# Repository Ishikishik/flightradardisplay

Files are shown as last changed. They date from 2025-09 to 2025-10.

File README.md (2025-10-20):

# フライトレーダー表示プロジェクト

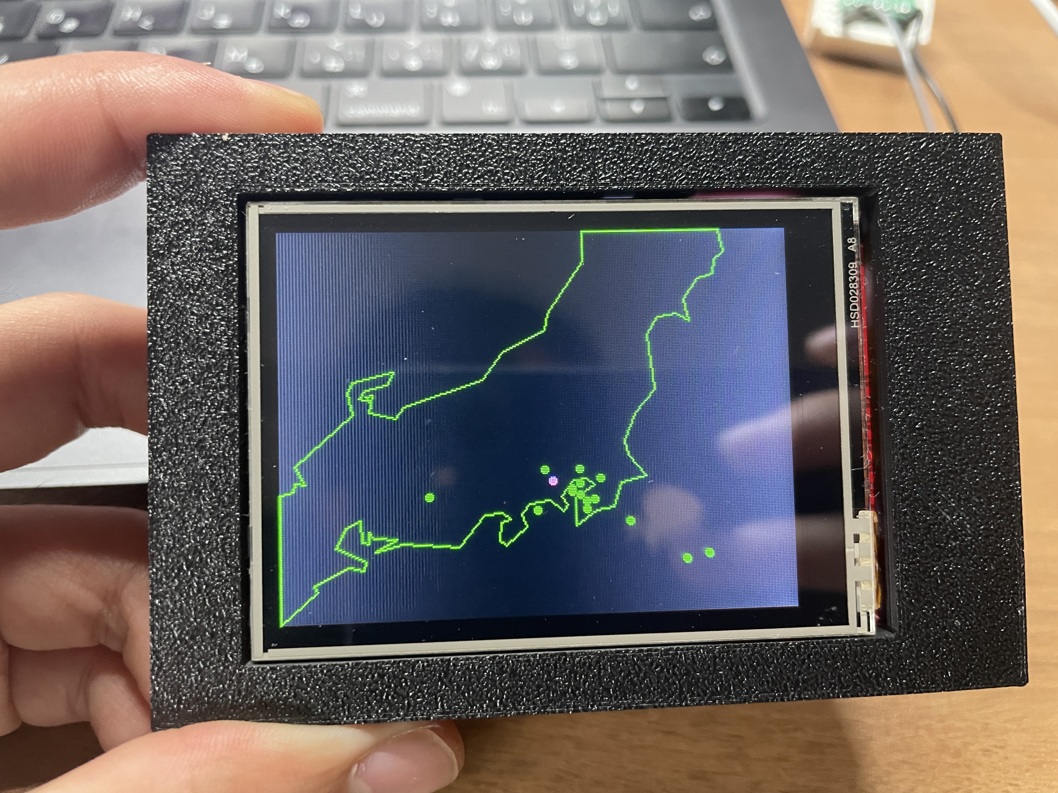
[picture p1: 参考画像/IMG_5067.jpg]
代替テキスト

代替テキスト

ESP32-C3 と小型液晶ディスプレイを使い、**フライトレーダーのフィード状況を表示するデバイス**です。  
ラズベリーパイを使った例よりも、**安価かつコンパクト**に構築できます。

---

## 使用部品

| 部品 | 説明・購入先 |
| ---- | --- |
| [ESP32-C3](https://akizukidenshi.com/catalog/g/g117493/) | メインマイコン |
| [1.54インチ TFT 液晶](https://akizukidenshi.com/catalog/g/g116265/) | 地図・便名表示用 |
| [USB Type-C コネクタ DIP 化キット](https://akizukidenshi.com/catalog/g/g115426/) | 電源・書き込み用 |
| コンデンサ / 抵抗 / 3端子レギュレータ | 電源安定化などに適宜使用 |
|ロータリースイッチ | 型番不明 |

---

## コード構成

### 1. 地図生成ツール(makemap)
- **`makemap.py`**  
  指定した緯度・経度範囲の白黒地図を生成します。  
  ご自分の地域に合わせてパラメータを設定してください。
- **`tolist.py`**  
  生成した白黒地図を **LCD に描画しやすい線形データ** に変換します。

### 2. 本体コード `kawaeyes`
- **`kawaeyes.ino`**  
  ESP32-C3 で動作するメインプログラム。
- **`library.cpp`**  
  - `setupwifi()`：Wi-Fi 接続処理  
  - `showairplane()`：飛行機の位置と便名を地図上に表示  
  - `showjson()`：便名と位置を文字のみで表示
- **`mapdata.cpp`**  
  東京都調布市（カワウソの住処）を例に `makemap` で生成した地図データ。

- **`secret.hpp`**  
  **Wi-Fi の SSID / パスワード / フィーダーの IP を定義するため、作成してください。**  
  下記の例を参考に、自分の環境に合わせて内容を編集します。

  ```cpp
  #ifndef SECRET_HPP
  #define SECRET_HPP

  #define SSID ""    // Wi-Fi SSID
  #define PASS ""    // Wi-Fi パスワード
  #define IP   ""    // フィーダーの IP
                          // 例: http://<IP>:8754/flights.json
                          // もしエンドポイントが異なる場合は
                          // getjson.cpp 内の showjson() を調整してください

  #endif

### 3. その他(hard,参考画像)
- **`hard`**  
  筐体の3Dデータ(.scadと.stlがある)
- **`参考画像`**  
  基板データはないがエクストリーム配線の様子を備忘録として残す。

  - **`repeater_flightradar`**  
  外でこの装置を動かしたい時に[このリポジトリ](https://github.com/Ishikishik/repeater_flightradar)をチェック!
  tailscaleに入ったpc(中間サーバー)からjsonをインターネットに公開して、他のネットワークからでもjsonを取得できる様にします。

---

## 参考リンク
- [LovyanGFX ライブラリ（LCD制御）](https://github.com/lovyan03/LovyanGFX)
- [ESP32 書き込み手順 (Qiita)](https://qiita.com/McbeEringi/items/b791399b03aba0929368)

---

## 使い方

1. **地図データ作成**  
   `makemap.py` で範囲を指定して白黒地図を生成 → `tolist.py` で LCD 用データに変換。

2. **ESP32-C3 へ書き込み**  
   生成した `mapdata.cpp` をプロジェクトに追加し、`kawaeyes.ino` をビルド＆書き込み。

3. **起動**  
   電源投入後、自動的に Wi-Fi へ接続し、フライトレーダーのフィードを取得して地図上に便名と位置を表示します。

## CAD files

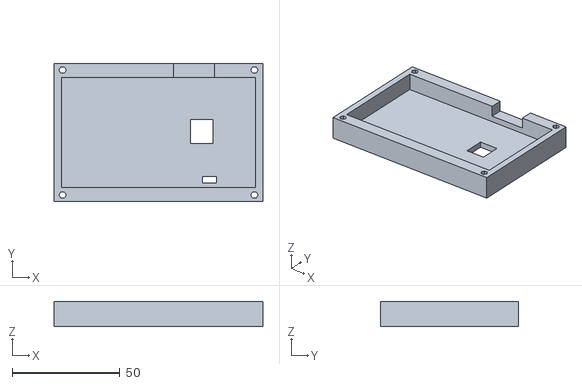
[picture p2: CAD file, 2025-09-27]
hard/under.stl
97.0 x 64.0 x 11.8

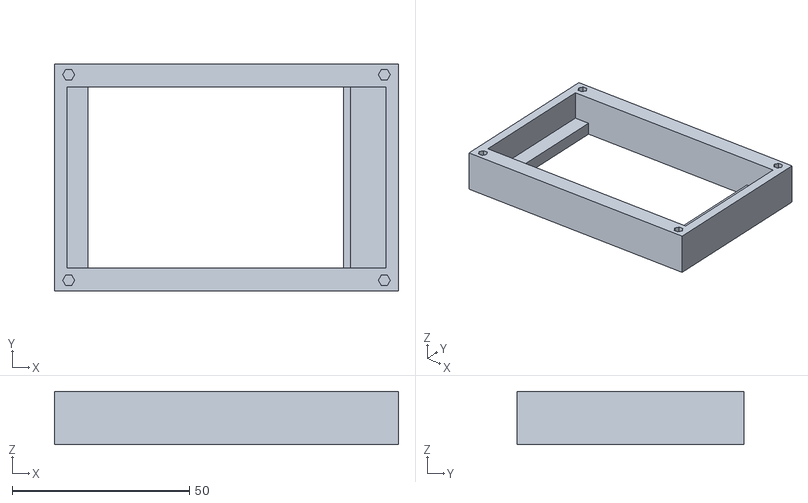
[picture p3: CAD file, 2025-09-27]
hard/top.stl
97.0 x 64.0 x 15.0

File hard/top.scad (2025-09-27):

//頭4.8(2.4)(2.9)mmネジ3.4(1.7)mmナット5.8(2.9)(3.4)mm
difference() {
    // 外枠（厚み6.5mm）
    cube([97, 64,15 ], center = true);//外装

    //ディスプレイ部
    translate([-3,0,-7.5])
    cube([72, 51,9], center = true);

    //本体部
    translate([0,0,7.5])
    cube([90, 51,21], center = true);

    //アンテナ部
    translate([0,0,7.5])
    cube([69.5, 51,4], center = true);

    //横端子部
    translate([40,0,0])
    cube([10, 51,12], center = true);


    //ネジ
    translate([95/2-3,60/2-1,0])
    cylinder(h = 10, r = 1.7, center = false);

    translate([-(95/2-3),60/2-1,0])
    cylinder(h = 10, r = 1.7, center = false);

    translate([95/2-3,-(60/2-1),0])
    cylinder(h = 10, r = 1.7, center = false);

    translate([-(95/2-3),-(60/2-1),0])
    cylinder(h = 10, r = 1.7, center = false);



   
}

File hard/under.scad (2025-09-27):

//頭4.8(2.4)(2.9)mmネジ3.4(1.7)mmナット5.8(2.9)(3.4)mm
//頭4.8(2.4)(2.9)mmネジ3.4(1.7)mmナット5.8(2.9)(3.4)mm
difference() {

    // 外枠（厚み6.5mm）
    translate([0,0,0])
    cube([97, 64,11.8 ], center = true);//外装


    //本体部
    translate([0,0,1.5])
    cube([90, 51,8.8], center = true);

    translate([90/2-21.4,-(64/2)+10,0])
    cube([6.5, 3,100], center = true);//端子

    translate([90/2-24.9,-(64/2)+32.5,0])
    cube([10.4, 11,100], center = true);//ロータリースイッチ

    translate([90/2-28.5,64/2,3.1])
    cube([19, 30,5.7], center = true);//アンテナ


    //ネジ
    translate([95/2-3,60/2-1,-20])
    cylinder(h = 100, r = 1.7, center = false);

    translate([-(95/2-3),60/2-1,-20])
    cylinder(h = 100, r = 1.7, center = false);

    translate([95/2-3,-(60/2-1),-20])
    cylinder(h = 100, r = 1.7, center = false);

    translate([-(95/2-3),-(60/2-1),-20])
    cylinder(h = 100, r = 1.7, center = false);

        //ネジ頭
    translate([95/2-3,60/2-1,-(11.8/2)])
    cylinder(h = 2, r = 3, center = false);

    translate([-(95/2-3),60/2-1,-(11.8/2)])
    cylinder(h = 2, r = 3, center = false);

    translate([95/2-3,-(60/2-1),-(11.8/2)])
    cylinder(h = 2, r = 3, center = false);

    translate([-(95/2-3),-(60/2-1),-(11.8/2)])
    cylinder(h = 2, r = 3, center = false);



   
}

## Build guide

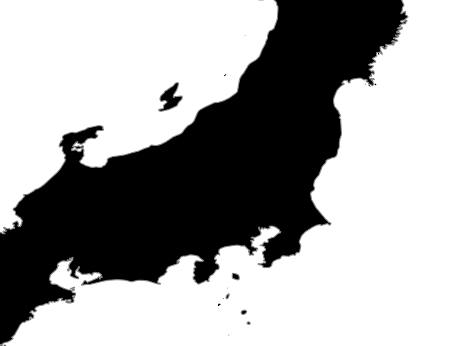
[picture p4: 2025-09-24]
makemap/map.png

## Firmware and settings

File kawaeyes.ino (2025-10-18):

#include <LovyanGFX.hpp>
#include "lgfxesp32c3.hpp"
#include "mapdata.hpp"
#include "library.hpp"
#include "secret.hpp"

MyLGFX lcd;  // LGFX → MyLGFX に変更
LGFX_Sprite mapSprite(&screenSprite);
LGFX_Sprite planeSprite(&screenSprite);
LGFX_Sprite screenSprite(&lcd);  // 新規スプライト

const float lon_min = 135.755; //画面西(左)端の経度
const float lon_max = 142.954; //画面東(右)端の経度
const float lat_min = 33.451; //画面下(南)端の経度
const float lat_max = 39.865; //画面上(北)端の経度
const float lon_home = 139.529; //アンテナの経度
const float lat_home = 35.651; //アンテナの緯度

const int button = 0; //表示切り替えを入れるgpioピン

//1度が何ピクセルに当たるかを計算(ディスプレイの大きさに合わせて調整)
const float pic_lon = 320 / (lon_max - lon_min); 
const float pic_lat = 240 / (lat_max - lat_min);
  
void setup(void) {
  Serial.begin(115200);
  lcd.init();
  lcd.setRotation(3);
  lcd.setBrightness(128);
  setupwifi(SSID, PASS);//wifiのセットアップ

  pinMode( button, INPUT );

  mapSprite.setColorDepth(2);
  mapSprite.createSprite(320, 240);  
  mapSprite.createPalette();
  mapSprite.setPaletteColor(0, 0x000000U);//黒
  mapSprite.setPaletteColor(1, 0x00FF00U);//緑
  mapSprite.setPaletteColor(2, 0xFF6CFFU);//ピンク


  planeSprite.setColorDepth(1);
  planeSprite.createSprite(320, 240);  
  planeSprite.createPalette();
  planeSprite.setPaletteColor(0, 0x000000U);//背景
  planeSprite.setPaletteColor(1, 0x00FF00U);//緑  
  
  screenSprite.setColorDepth(2);
  screenSprite.createSprite(320, 240);  
  screenSprite.createPalette();
  screenSprite.setPaletteColor(0, 0x000000U);//黒
  screenSprite.setPaletteColor(1, 0x00FF00U);//緑
  screenSprite.setPaletteColor(2, 0xFF6CFFU);//ピンク  


  //自宅の位置をピクセル座標化
  const int lonpic_home = (lon_home - lon_min) * pic_lon;
  const int latpic_home = (lat_max - lat_home) * pic_lat;
  // Sprite初期化：画面全体と同じサイズ
  mapSprite.fillScreen(0);
  for (int i = 0; i < NUM_LINES; ++i) {
    mapSprite.drawLine(lines[i][0], lines[i][1], lines[i][2], lines[i][3], 1);
  }
  //自宅に丸い点を打つ
  mapSprite.fillCircle(lonpic_home, latpic_home , 2, 2);  
  delay(10000);
}

void loop(void) {
  int buttonState = digitalRead(button);  // HIGH / LOW を取得

  if (buttonState == HIGH) {
    // ボタンが押されていない（プルダウン構成の場合）なら showjson
    showjson(IP);
  } else {
    // ボタンが押されている（LOW）なら showairplane
    showairplane(IP, lon_min, pic_lon, lat_max, pic_lat);
    //showjson(IP);//デバック
  }
  delay(1000);  //更新間隔
}


//6=showplane
//5=showjson

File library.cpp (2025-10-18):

#include "library.hpp"

// 便情報の構造体を定義
struct FlightInfo {
  char callsign[7];  // 便名（最大9文字＋NULL）
  float latitude;     // 緯度
  float longitude;    // 経度
};

// 100機分のデータを格納できる配列
FlightInfo flights[100];

WiFiClient client;       // clientの実体もここに

void setupwifi(const char* ssid, const char* pass) {
  WiFi.begin(ssid, pass);

  int16_t cx = lcd.width()  / 2;
  int16_t cy = lcd.height() / 2;
  lcd.setTextColor(TFT_GREEN, TFT_BLACK);  // 緑文字・黒背景
  lcd.setTextSize(2);                      // お好みでサイズ変更

  while (WiFi.status() != WL_CONNECTED) {
    lcd.setCursor(cx - 60, cy - 8);         // 文字幅に合わせてオフセット
    lcd.print("Connecting WiFi...");
    delay(500);
  }
  // 接続成功時
  lcd.fillRect(cx - 80, cy - 8, 160, 16, TFT_BLACK); // 前の文字を消す
  lcd.setCursor(cx - 70, cy - 8);
  lcd.print("Connection Success");
}





/*航空機とコードを地図上に表示するコード*/
void showairplane(const char* ip, float lon_min, float pic_lon, float lat_max, float pic_lat){
  // 正しい形式でIPとポートを分けて接続
  if (client.connect(ip, 8754)) {//自宅8754,外部80
    client.println("GET /flights.json HTTP/1.0");//自宅:"GET /flights.json HTTP/1.0"外部:"GET / HTTP/1.1"
    client.print("Host: ");//"Host: "
    client.println(ip);
    client.println("Connection: close");
    client.println();
    // HTTPヘッダをスキップ
    while (client.connected()) {
      String line = client.readStringUntil('\n');
      if (line == "\r") break;
    }

    // 本文をすべて読み込む
    String payload = "";
    while (client.available()) {
      payload += client.readString();
    }

    // JSONバッファを確保（容量は必要に応じて調整）
    const size_t capacity = 64 * JSON_OBJECT_SIZE(100) + 10000;
    DynamicJsonDocument doc(capacity);

    DeserializationError error = deserializeJson(doc, payload);
    if (error) {
      Serial.print("JSON Error: ");
      Serial.println(error.f_str());
      return;
    }

planeSprite.fillScreen(0);

for (JsonPair kv : doc.as<JsonObject>()) {
  JsonArray data = kv.value().as<JsonArray>();
  if (data[1].as<float>() == 0 || data[2].as<float>() == 0) {
    continue;   
  }
  const char* callsign = data[16];
  float lat = (lat_max - data[1].as<float>()) * pic_lat;
  float lon = (data[2].as<float>() - lon_min) * pic_lon;


  if (lat != 0 && lon != 0 && strlen(callsign) > 0) {
    planeSprite.fillCircle(lon, lat , 2, 1); 
  }
}
  } else {
    delay(1000);
    showairplane(ip, lon_min, pic_lon, lat_max, pic_lat); 
    return;
  }
  screenSprite.fillScreen(0);
  mapSprite.pushSprite(0, 0);                    
  planeSprite.pushSprite(0, 0 , 0);
  screenSprite.pushSprite(0,0);
}





















/*コールサインをそのまま表示するコード*/
void showjson(const char* ip){
  // 正しい形式でIPとポートを分けて接続
  if (client.connect(ip, 8754)) {//自宅8754,外部80
    client.println("GET /flights.json HTTP/1.0");//自宅:"GET /flights.json HTTP/1.0"外部:"GET / HTTP/1.1"
    client.print("Host: ");//"Host: "
    client.println(ip);
    client.println("Connection: close");
    client.println();
    // HTTPヘッダをスキップ
    while (client.connected()) {
      String line = client.readStringUntil('\n');
      if (line == "\r") break;
    }

    // 本文をすべて読み込む
    String payload = "";
    while (client.available()) {
      payload += client.readString();
    }

    // JSONバッファを確保（容量は必要に応じて調整）
    const size_t capacity = 64 * JSON_OBJECT_SIZE(100) + 10000;
    DynamicJsonDocument doc(capacity);

    DeserializationError error = deserializeJson(doc, payload);
    if (error) {
      Serial.print("JSON Error: ");
      Serial.println(error.f_str());
      return;
    }
  int y = 10; // 最初の表示位置Y座標
  planeSprite.fillScreen(TFT_BLACK);  // 画面をクリア

for (JsonPair kv : doc.as<JsonObject>()) {
  JsonArray data = kv.value().as<JsonArray>();

  const char* callsign = data[16];
  float lat = data[1];
  float lon = data[2];

  if (lat != 0 && lon != 0 && strlen(callsign) > 0) {
    // 1行に1件表示（例：JJ5STB: 35.12, 139.44）
    planeSprite.setCursor(10, y);
    planeSprite.setTextColor(1, 0);
    planeSprite.setTextSize(1);
    planeSprite.printf("%s: %.2f, %.2f", callsign, lat, lon);

    y += 12;  // 次の行へ（文字サイズ1なら12ピクセルくらい空ける）
    
    // 画面の高さを超えたら、それ以上は表示しない（表示崩れ対策）
    if (y > lcd.height() - 12) break;
  }
}
  } else {
    delay(1000);
    showjson(ip); // もう一度だけ再試行
    return;
  }
  screenSprite.fillScreen(0);                  
  planeSprite.pushSprite(0, 0 , 0);
  screenSprite.pushSprite(0,0);
}

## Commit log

2025-06-21 displayに映すまで
2025-06-21 背景に日本地図を描写
2025-06-23 地図を修正
2025-06-26 飛行機を映す関数を作成
2025-09-24 spriteを作る手前
    [partitions.csv, top.scad, under.scad]
2025-09-27 地図と飛行機の位置を同時に表示
    [top.scad, top_v5.stl, under.scad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]
2025-09-27 新たなスプライトに書き込むように変更
2025-09-27 ボタンが使えるように追加
2025-09-27 showjsonのちらつきを改善
2025-09-27 参考画像、readme.mdを更新
    [top.stl, top_v5.stl, under.stl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]
2025-09-27 キャッシュを消去
    [partitions.csv]
2025-09-29 read.mdに画像を追加
2025-10-18 外部で動かせる様に設定を追加＋wifi接続状態を表示するよう仕様変更
2025-10-20 readmeにrepeaterについて記載
2026-11-06 websocketの実装を開始
2026-11-10 actions確認
2026-11-10 GitHub ActionsからTailscaleに接続する
2026-11-10 Tailscale経由でPiへの疎通を確認する
2026-11-10 GitHub ActionsからPiへのSSH接続を確認する
2026-11-11 サーバーの情報を変更するように改良
2026-11-11 flight情報を配信
2026-11-11 flight情報を配信2
2026-11-11 バイナリで配信
2026-11-11 デプロイ時にsetup.shを実行する
2026-11-11 デプロイ後に setup.sh を実行してサービスを再起動する
2026-11-11 ver2が完成
